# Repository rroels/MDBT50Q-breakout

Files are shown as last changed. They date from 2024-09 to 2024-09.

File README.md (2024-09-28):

# Raytac MDBT50Q (nRF52840) Breakout Board

> [!WARNING]
> The information and material (code, designs, files, ...) are provided "AS IS". We make no representation or warranty of any kind, express or implied, regarding the accuracy, adequacy, validity, reliability, availability, or completeness of any information or material. Use this at your own risk.

## Introduction

This is a breakout board for the Raytac MDBT50Q, which is small module based on the Nordic nRF52840 microcontroller.

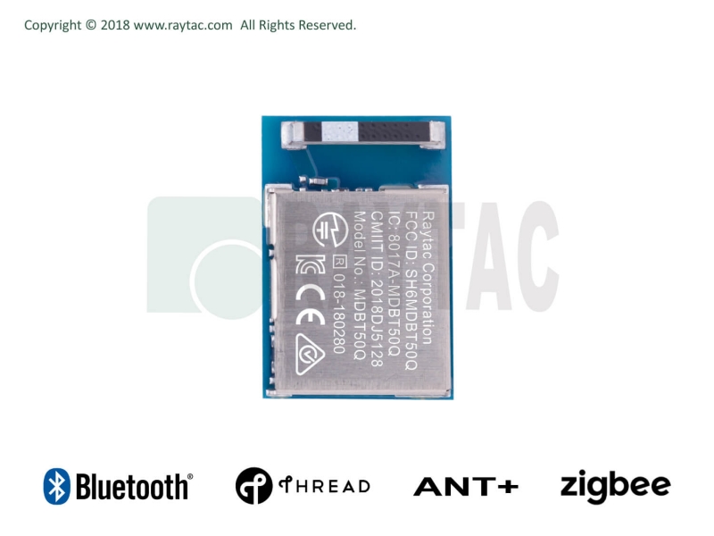
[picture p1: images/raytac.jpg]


[https://www.raytac.com/product/ins.php?index_id=24](https://www.raytac.com/product/ins.php?index_id=24)

This breakout board works with all three variants, since the only difference is their antenna:

* MDBT50Q-1MV2
* MDBT50Q-U1MV2
* MDBT50Q-P1MV2

Note that these modules are sometimes sold by other vendors, who put their own branding on the module:

* [https://www.adafruit.com/product/4078](https://www.adafruit.com/product/4078)
* [https://www.seeedstudio.com/MDBT50Q-1M-nRF52840-Based-BLE-Module-p-3147.html](https://www.seeedstudio.com/MDBT50Q-1M-nRF52840-Based-BLE-Module-p-3147.html)

This breakout board adds some power management and exposes most of the pins:

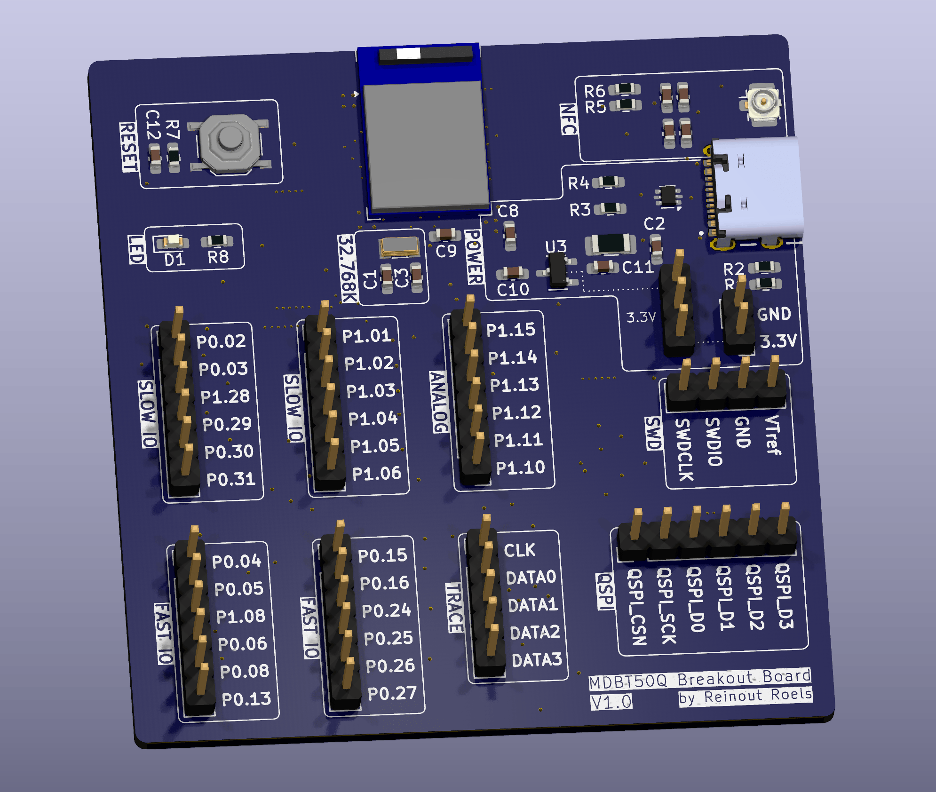
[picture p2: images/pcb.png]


> [!WARNING]
> GPIO pins marked as "SLOW IO" are not slow per se. However, Nordic does not recommend using them for high frequency signals (e.g. SPI or I2C), as they may cause, or be subject to, interference (they are closest to the radio of the nRF52840).

## Change Log

* v1.0
  * Initial design 

## Design Considerations

* on-board 5V to 3.3V converter
* external 32.768K crystal (optional for the MDBT50Q module)
* ESD diode 
* reset button
* 1 LED 

## Schematics 

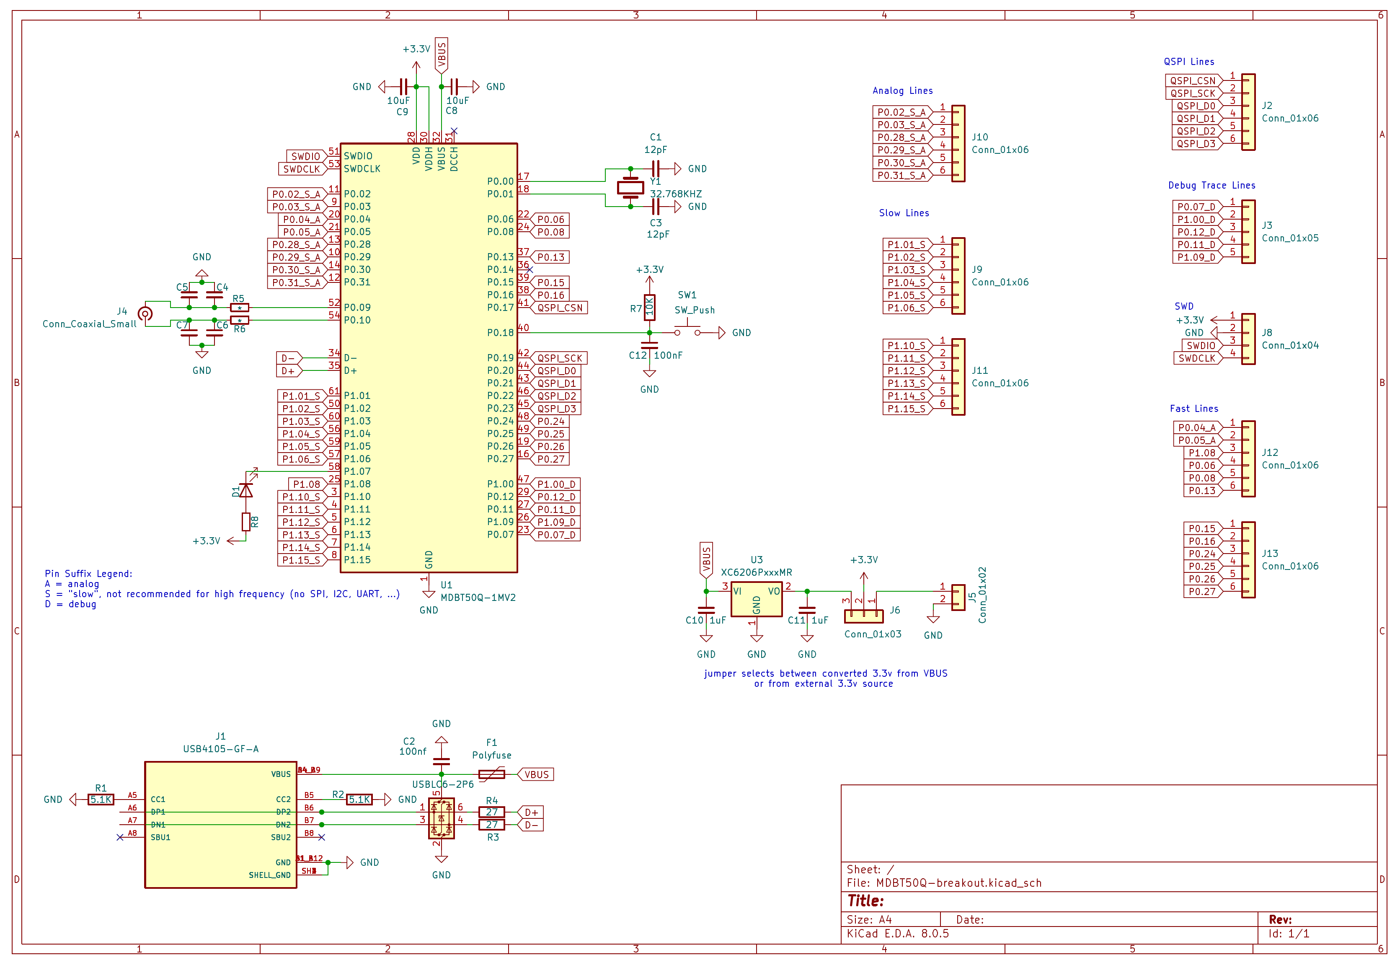
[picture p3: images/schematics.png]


> [!WARNING]
> GPIO pins marked as "SLOW IO" are not slow per se. However, Nordic does not recommend using them for high frequency signals (e.g. SPI or I2C), as they may cause, or be subject to, interference (they are closest to the radio of the nRF52840).

## How to Obtain the Physical PCB



The Gerber file is in this repository (`gerber/MDBT50Q-breakout.zip`). Simply upload this file a PCB manufacturer of your choice (JLPCB, PCBWay, ...), and you they will make it for you for as low as \$5 for 5 pieces (with the cheapest shipping option, which can take a few weeks).

For JLCPCB, select the order number option where they will replace "JLCJLCJLCJLC" on the board with the actual order number.

> [!WARNING]
> Note that will still have to solder the components onto the PCB yourself!

## How to Edit Design

Everything you need to edit this design in KiCad 8 is included in the repository.

However, this project uses symbols, footprints and 3D models from [Component Search Engine](https://componentsearchengine.com/). Their license allows us to do pretty much whatever we want with them, except redistributing them. For this reason I can't include them in this repository.

If you would like to edit the design yourself, you will need to download the following component libraries from [https://componentsearchengine.com/](https://componentsearchengine.com/) (it's free!):

* [https://componentsearchengine.com/part-view/TS-1187A-C-D-B/XKB%20Connectivity](https://componentsearchengine.com/part-view/TS-1187A-C-D-B/XKB%20Connectivity)

You also need these from SnapEDA:

* [https://www.snapeda.com/parts/21296912/TE%20Connectivity/view-part/?ref=te_in&t=USB4105-GF-A&con_ref=None](https://www.snapeda.com/parts/21296912/TE%20Connectivity/view-part/?ref=te_in&t=USB4105-GF-A&con_ref=None)

From the downloaded zip files, move the content of the `KiCad` and `3D` subfolders into the project structure, so that the end-result looks like this:

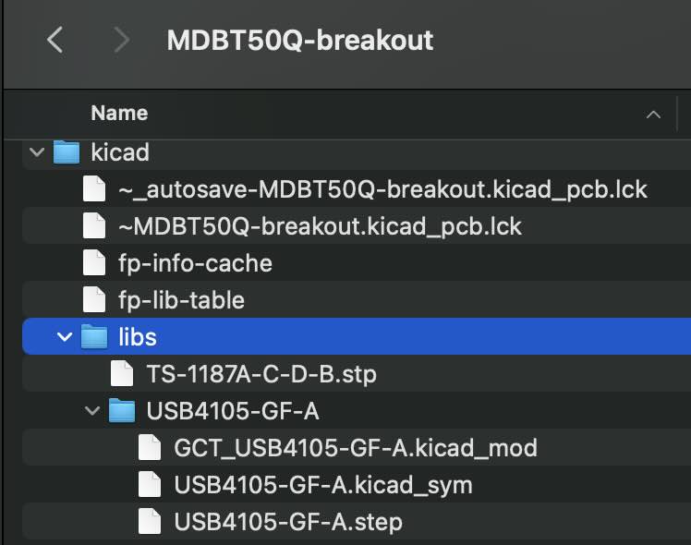
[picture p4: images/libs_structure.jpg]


The KiCad project is configured to look for these files in these locations, using relative paths, so no changes to the project itself are required.

## Future Work

* Improve routing
	* use more than 2 layer PCBs
* Add another push button for better compatibility with the Adafruit nRF52 bootloader	

## Sources

* [https://www.raytac.com/product/ins.php?index_id=24](https://www.raytac.com/product/ins.php?index_id=24)

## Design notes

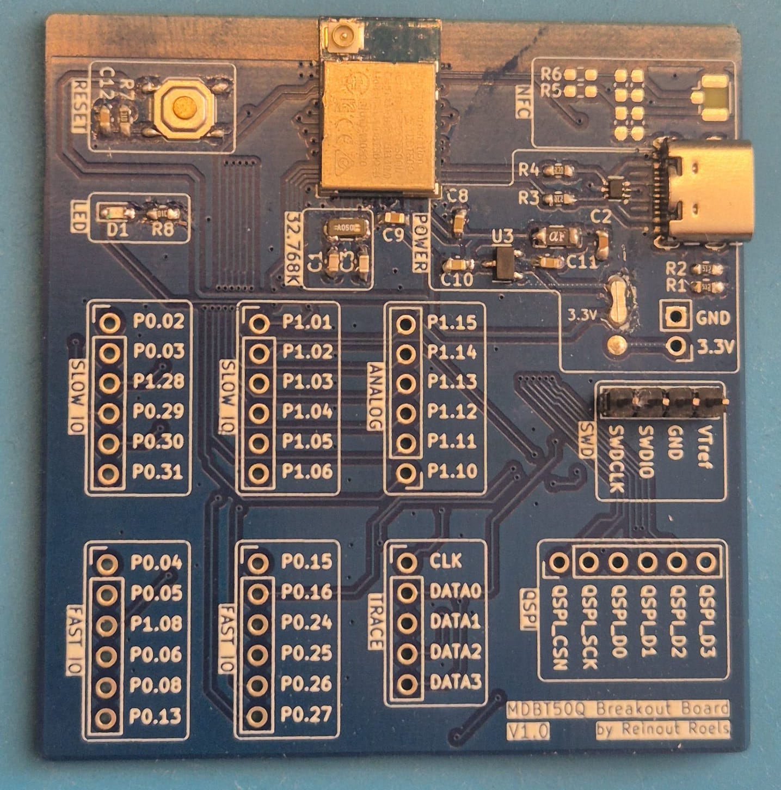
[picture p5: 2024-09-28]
images/board.jpg

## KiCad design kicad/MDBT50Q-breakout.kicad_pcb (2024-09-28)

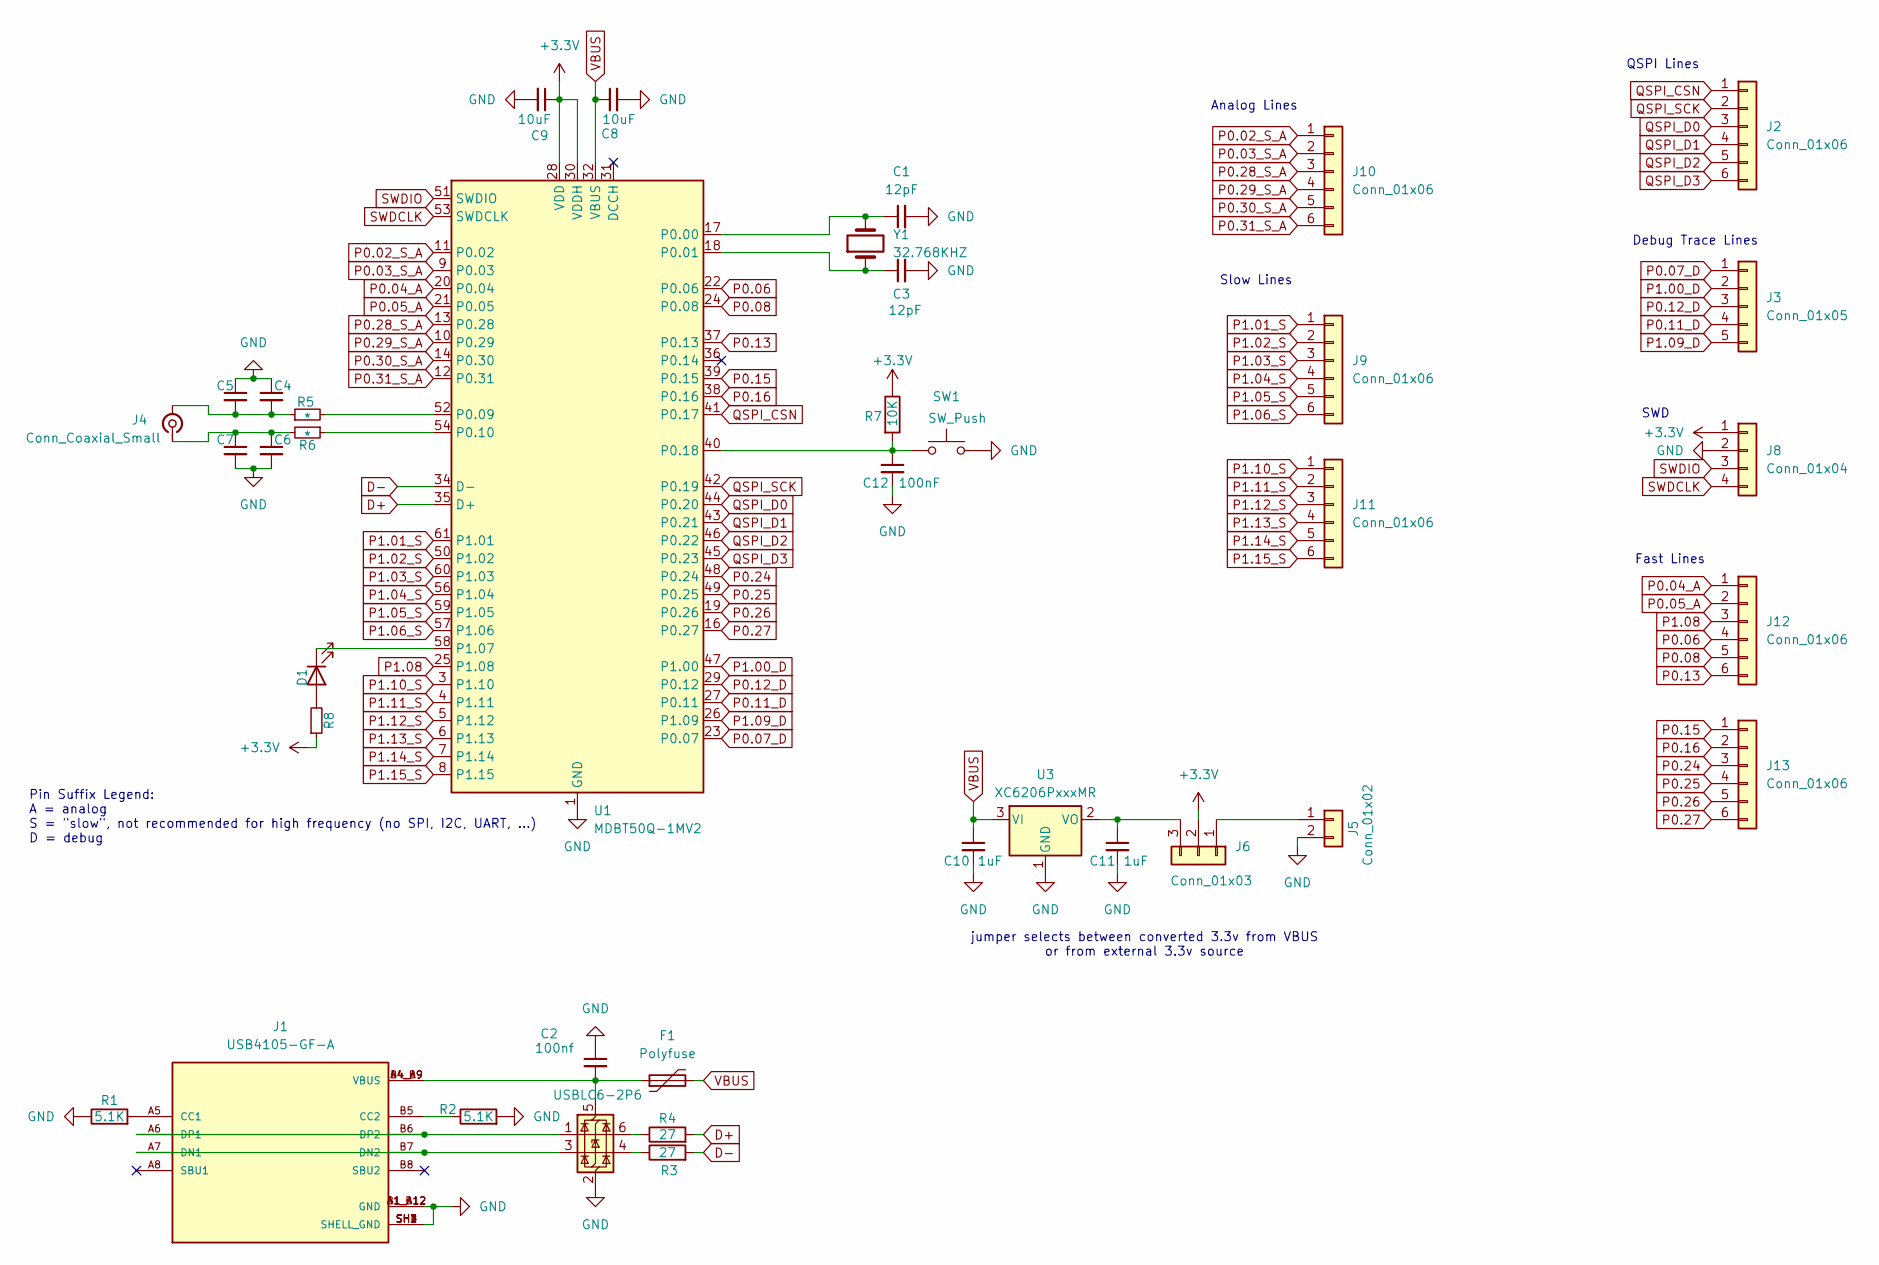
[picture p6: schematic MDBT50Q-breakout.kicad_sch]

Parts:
C1, C3: 12pF; C_0603_1608Metric_Pad1.08x0.95mm_HandSolder
C2: 100nf; C_0603_1608Metric_Pad1.08x0.95mm_HandSolder
C4, C5, C6, C7: C_Small; C_0603_1608Metric_Pad1.08x0.95mm_HandSolder
C8, C9: 10uF; C_0603_1608Metric_Pad1.08x0.95mm_HandSolder
C10, C11: 1uF; C_0603_1608Metric_Pad1.08x0.95mm_HandSolder
C12: 100nF; C_0603_1608Metric_Pad1.08x0.95mm_HandSolder
D1: LED; LED_0603_1608Metric_Pad1.05x0.95mm_HandSolder
F1: Polyfuse; Fuse_1206_3216Metric_Pad1.42x1.75mm_HandSolder
J1: USB4105-GF-A; GCT_USB4105-GF-A; PARTREV B4
J2, J9, J10, J11, J12, J13: Conn_01x06; PinHeader_1x06_P2.54mm_Vertical
J3: Conn_01x05; PinHeader_1x05_P2.54mm_Vertical
J4: Conn_Coaxial_Small; U.FL_Hirose_U.FL-R-SMT-1_Vertical
J5: Conn_01x02; PinHeader_1x02_P2.54mm_Vertical
J6: Conn_01x03; PinHeader_1x03_P2.54mm_Vertical
J8: Conn_01x04; PinHeader_1x04_P2.54mm_Vertical
R1, R2: 5.1K; R_0603_1608Metric_Pad0.98x0.95mm_HandSolder
R3, R4: 27; R_0603_1608Metric_Pad0.98x0.95mm_HandSolder
R5, R6: *; R_0603_1608Metric_Pad0.98x0.95mm_HandSolder
R7: 10K; R_0603_1608Metric_Pad0.98x0.95mm_HandSolder
R8: R_Small; R_0603_1608Metric_Pad0.98x0.95mm_HandSolder
SW1: SW_Push; SW_Push_1P1T_XKB_TS-1187A
U1: MDBT50Q-1MV2; Raytac_MDBT50Q
U2: USBLC6-2P6; SOT-666
U3: XC6206PxxxMR; SOT-23-3
Y1: 32.768KHZ; Crystal_SMD_3215-2Pin_3.2x1.5mm

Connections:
+3.3V: C9.1, J6.2, J8.1, R7.1, R8.1, U1.28 (VDD), U1.30 (VDDH)
D+: R4.2, U1.35 (D+)
D-: R3.2, U1.34 (D-)
GND: C1.2, C2.1, C3.2, C4.1, C5.1, C6.2, C7.2, C8.2, C9.2, C10.2, C11.2, C12.2, J1.A1_B12 (GND), J1.B1_A12 (GND), J1.SH1 (SHELL_GND), J1.SH2 (SHELL_GND), J1.SH3 (SHELL_GND), J1.SH4 (SHELL_GND), J5.2, J8.2, R1.1, R2.2, SW1.2, U1.1 (GND), U1.2 (GND), U1.15 (GND), U1.33 (GND), U1.55 (GND), U2.2 (GND), U3.1 (GND)
unnamed: D1.2 (A), R8.2
unnamed: D1.1 (K), U1.58 (P1.07)
unnamed: J1.A5 (CC1), R1.2
unnamed: J1.B5 (CC2), R2.1
unnamed: J1.A7 (DN1), J1.B7 (DN2), U2.3 (I/O2)
unnamed: J1.A6 (DP1), J1.B6 (DP2), U2.1 (I/O1)
unnamed: C4.2, C5.2, J4.2 (Ext), R5.1
unnamed: C6.1, C7.1, J4.1 (In), R6.2
unnamed: J5.1, J6.1
unnamed: C11.1, J6.3, U3.2 (VO)
unnamed: R3.1, U2.4 (I/O2)
unnamed: R4.1, U2.6 (I/O1)
unnamed: C1.1, U1.17 (P0.00), Y1.2
unnamed: C3.1, U1.18 (P0.01), Y1.1
unnamed: R5.2, U1.52 (P0.09)
unnamed: R6.1, U1.54 (P0.10)
unnamed: C12.1, R7.2, SW1.1, U1.40 (P0.18)
unnamed: C2.2, F1.1, J1.A4_B9 (VBUS), J1.B4_A9 (VBUS), U2.5 (VBUS)
P0.02_S_A: J10.1, U1.11 (P0.02)
P0.03_S_A: J10.2, U1.9 (P0.03)
P0.04_A: J12.1, U1.20 (P0.04)
P0.05_A: J12.2, U1.21 (P0.05)
P0.06: J12.4, U1.22 (P0.06)
P0.07_D: J3.1, U1.23 (P0.07)
P0.08: J12.5, U1.24 (P0.08)
P0.11_D: J3.4, U1.27 (P0.11)
P0.12_D: J3.3, U1.29 (P0.12)
P0.13: J12.6, U1.37 (P0.13)
P0.15: J13.1, U1.39 (P0.15)
P0.16: J13.2, U1.38 (P0.16)
P0.24: J13.3, U1.48 (P0.24)
P0.25: J13.4, U1.49 (P0.25)
P0.26: J13.5, U1.19 (P0.26)
P0.27: J13.6, U1.16 (P0.27)
P0.28_S_A: J10.3, U1.13 (P0.28)
P0.29_S_A: J10.4, U1.10 (P0.29)
P0.30_S_A: J10.5, U1.14 (P0.30)
P0.31_S_A: J10.6, U1.12 (P0.31)
P1.00_D: J3.2, U1.47 (P1.00)
P1.01_S: J9.1, U1.61 (P1.01)
P1.02_S: J9.2, U1.50 (P1.02)
P1.03_S: J9.3, U1.60 (P1.03)
P1.04_S: J9.4, U1.56 (P1.04)
P1.05_S: J9.5, U1.59 (P1.05)
P1.06_S: J9.6, U1.57 (P1.06)
P1.08: J12.3, U1.25 (P1.08)
P1.09_D: J3.5, U1.26 (P1.09)
P1.10_S: J11.1, U1.3 (P1.10)
P1.11_S: J11.2, U1.4 (P1.11)
P1.12_S: J11.3, U1.5 (P1.12)
P1.13_S: J11.4, U1.6 (P1.13)
P1.14_S: J11.5, U1.7 (P1.14)
P1.15_S: J11.6, U1.8 (P1.15)
QSPI_CSN: J2.1, U1.41 (P0.17)
QSPI_D0: J2.3, U1.44 (P0.20)
QSPI_D1: J2.4, U1.43 (P0.21)
QSPI_D2: J2.5, U1.46 (P0.22)
QSPI_D3: J2.6, U1.45 (P0.23)
QSPI_SCK: J2.2, U1.42 (P0.19)
SWDCLK: J8.4, U1.53 (SWDCLK)
SWDIO: J8.3, U1.51 (SWDIO)
VBUS: C8.1, C10.1, F1.2, U1.32 (VBUS), U3.3 (VI)

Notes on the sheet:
Slow Lines
SWD
jumper selects between converted 3.3v from VBUS or from external 3.3v source
Debug Trace Lines
Analog Lines
QSPI Lines
Fast Lines
Pin Suffix Legend: A = analog S = "slow", not recommended for high frequency (no SPI, I2C, UART, ...) D = debug

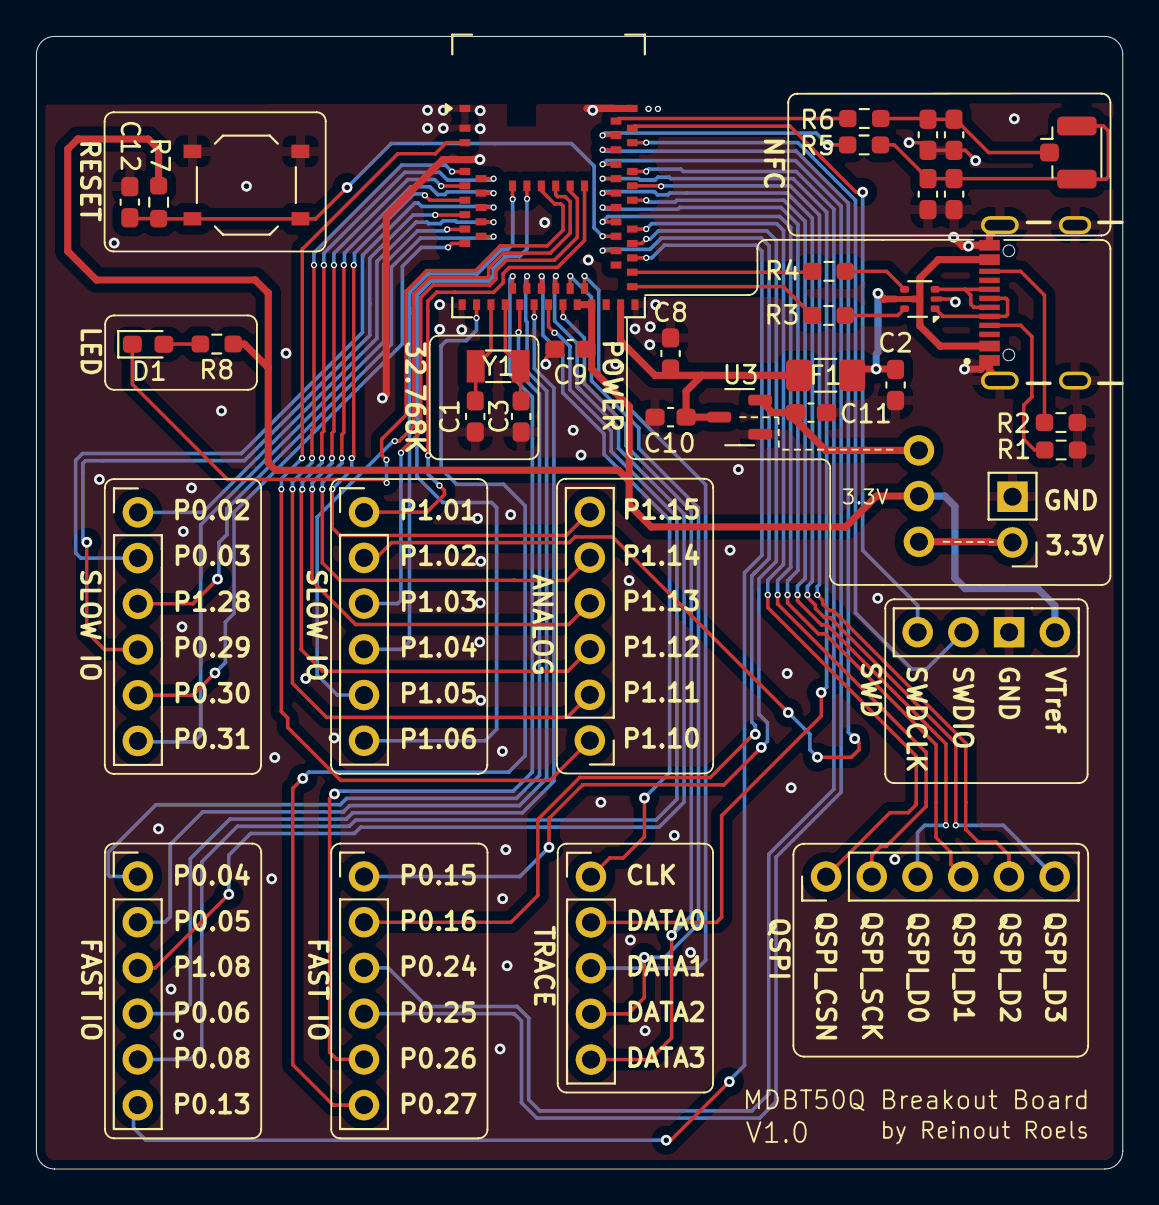
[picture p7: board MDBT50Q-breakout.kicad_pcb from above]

Board: 2 copper layers, 60.4 x 62.9 mm, 39 parts (0 on the bottom side), 66 nets.
